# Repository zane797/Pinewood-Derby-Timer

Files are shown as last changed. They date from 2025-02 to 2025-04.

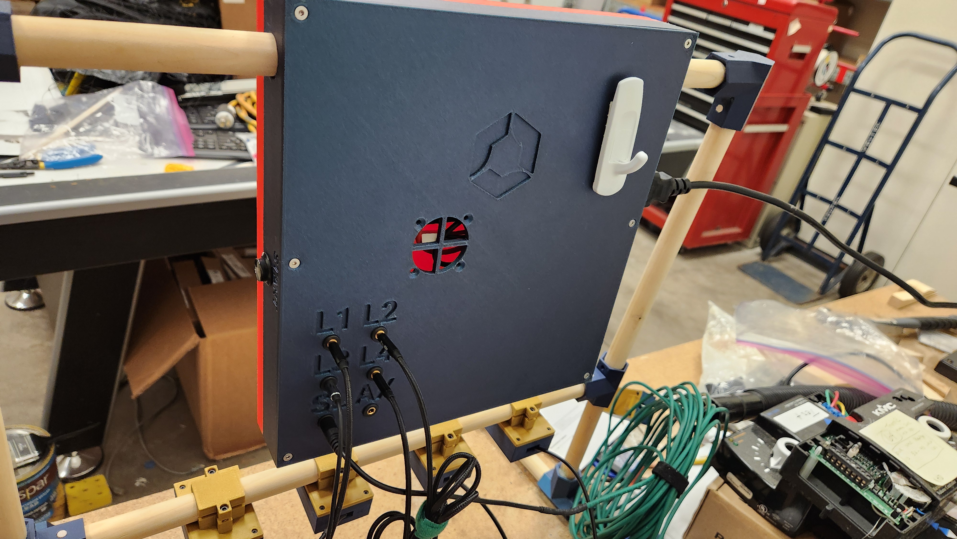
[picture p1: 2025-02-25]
Photos/Exterior/20250219_124340.jpg

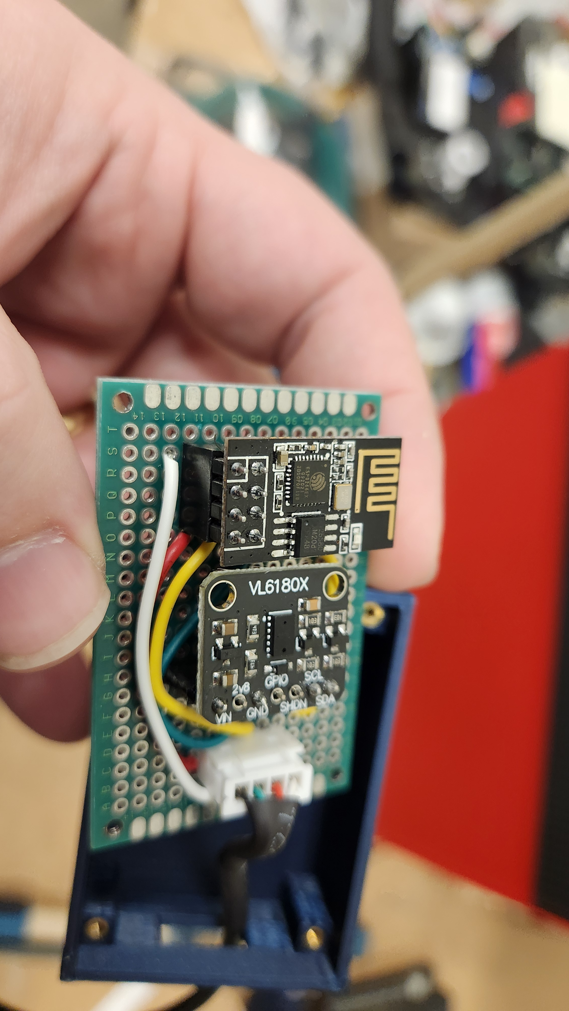
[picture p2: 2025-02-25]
Photos/Interior/20250219_135851.jpg

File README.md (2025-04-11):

# Pinewood-Derby-Timer
A firmware and case design for a DIY pinewood derby timer. Long term this will integrate with the Derby Net race management software.

# Bill of Materials

## Main Control Box

|Description|Part|Link|
|-|-|-|
|Main Microcontroller|Raspberry Pi Pico W|[Aliexpress](https://www.aliexpress.us/item/3256805317728363.html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)|
|Wifi and Derby Net Host|Raspberry Pi Zero W|[Aliexpress](https://www.aliexpress.us/item/3256805605866860.html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)
|Timer Screen|P4 64x32 LED Matrix|[Aliexpress](https://www.aliexpress.us/item/3256804589638597.html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)|
|5V PSU|Meanwell LRS-100-5|[Aliexpress](https://www.aliexpress.us/item/3256805881564763.html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)|
|Pin Connections|Assorted 4 pin JST 2.54 Headers|[Aliexpress](https://www.aliexpress.us/item/3256806894018733.html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)|
|Sensor Connections|3.5 MM Jack|[Aliexpress](https://www.aliexpress.us/item/3256803435015141.html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)|
|Voltage Regulator|LD1117V33|[Aliexpress](https://www.aliexpress.us/item/3256806308155209.html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)|
|Starting Button|16 mm Round Push Button|[Aliexpress](https://www.aliexpress.us/item/2255800895415537.html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)|
|Power Plug|C14 Plug Socket|[Aliexpress](https://www.aliexpress.us/item/2251832772820835.html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)

## Sensor Module

|Description|Part|Link|
|-|-|-|
|TOF Sensor|VL6180X|[Aliexpress](https://www.aliexpress.us/item/3256806030301281.html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)|
|Sensor Microcontroller|ESP8266-ESP01S|[Aliexpress](https://www.aliexpress.us/item/3256805668764137.html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)
|Main Board Connection|3.5 mm TRRS Female|[Aliexpress](https://www.aliexpress.us/item/3256806426250837.html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)|
|Pin Connections|Assorted 4 pin JST 2.54 Headers|[Aliexpress](https://www.aliexpress.us/item/3256806894018733.html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)|
|Main Board Cable|3.5 MM TRRS Cable 1ft|[Aliexpress](https://www.aliexpress.us/item/2255799918035646.html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)

## Starting Line
|Description|Part|Link|
|-|-|-|
|Reed Switch|GPS-14A NO|[Aliexpress](https://www.aliexpress.us/item/3256808008425913.html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)|

Not included are assorted resistors and capacitors, as are documented in the circuit schematic.

# Overall Design

## Main Control Box

The goal for this box was to create a replacement Pinewood Derby Track Timer and add a race management software called DerbyNet. The core of this is a Raspberry Pi Pico W with a Raspberry Pi Zero W. The plan is to create a system that reliably times differences of less than 50 ms. The sensors read at ~100Hz and require 2 successive detections of a car, to avoid false readings at the high speed. This means the effective sensing time is roughly .02 seconds. This meets the design goal of sensing times of less than 0.05 seconds. One major design goal was a simple to setup system. The existing timer required precise alignment of lighting with the sensors below the track and a difficult to 

The original design included an I2C multiplexer routed directly to the VL6180Xs in the sensor modules. This led to sensing issues and bad data reads. I suspect this was due to using I2C through several connections and wire types. This was removed and in it's place I am using simple digital command and input signal lines to command the ESP-01S modules accordingly. These have been much more reliable and once the architecture change happened reliability went up significantly.

The display is a LED matrix screen using a HUB75 interface which makes the wiring more painful than the I2C interface most lightweight hobbyists like myself are used to for project displays. I think if I were to make a version 2, I would create a custom PCB for the PCB and include a HUB75 socket to make the wiring process much easier. Aside from the interface, the LED Matrix as a display worked incredibly well for my. It's easily readable even in well lit rooms, and fit perfectly in my model. I think the only thing I would change is pulling in the display a bit so it doesn't protrude from the chassis.

## Sensor Module

The sensor module started as just a VL6180X on a protoboard, with a couple pull up resistors and a JST connector for the wire. This turned out to be a reliability nightmare and for the initial release I updated it to have a dedicated ESP8266 in a ESP-01S package, which had exactly the number of IO pins for what I needed. The ESP-01S interfaced with the VL6180X directly and signaled the main control box when a car was detected.

# Lessons Learned/V2 Plans

I am unlikely to return to this project soon, but when I do these are some of the items I'd like to implement in the future to streamline the design for anyone else that makes it.

## Lesson's Learned
- While I2C can be used over longer distances, it can be unreliable when jumped through multiple connections with inconsistent capacitance on each leg. I should have planned on something more robust, RS485, or something simple like a simple Digital Output and Digital Input like I ended up with much earlier on.
- I was using DIY TRRS cables using ethernet and DIY oriented 3.5 mm TRRS connectors. This was terrible in terms of reliability. I should have spent a few bucks per cable and gone to store bought from the start. Just because you can DIY doesn't mean you should.
- 

## Next Steps
- [ ] Develop a custom to streamline construction. Right now the main PCB is an exremely manual process. A custom PCB would be both easier to work with and have a smaller footprint. This could also leverage something like the [Raspberry Pi Pico Stamp](https://shop.pimoroni.com/products/rp2040-stamp?variant=39567567028307) to further reduce footprint.
- [ ] [DerbyNet](https://derbynet.org/) Integration. Leverage the second core on the Pi Pico to implement code to tie into the Derby Net instance being hosted on the Raspberry Pi Zero W over USB serial.
- [ ] Consider alternative sensors to further drive down the timing resolution with a goal of sub 10 ms. This will need to meet the design criteria of simple to set up, so it must be only top mounted and not include additional parts under the track. i.e. Lights shining from below the track to trigger an occlusion sensor would fail as it requires the alignment of two separate assemblies.
- [ ] Redesign the electronics enclosure. It always just the fastest and easiest design I could make so I could focus on firmware. It is a bit ponderous on the dowel and space could be used more efficiently.
- [ ] Redesign the frame. I like the concept of a simple modular frame assembly. I did notice that dowels changed in shape much more than I expected over time, likely due to moisture changes. I'd like to improve the geometry of the joints so that 3/4" dowels with some shrinkage could be pressfit into them.

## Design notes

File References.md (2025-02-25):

# Libraries Used in the Code
[Adafruit ProtoMatter](https://github.com/adafruit/Adafruit_protomatter)

[Raspberry Pi Pico Support](https://github.com/earlephilhower/arduino-pico)

[VL6180X](https://github.com/pololu/vl6180x-arduino)

[ESP8266 Support](https://github.com/esp8266/Arduino)

# Race Management Software
[DerbyNet (Not Fully Implemented)](https://derbynet.org/builds/docs.php)

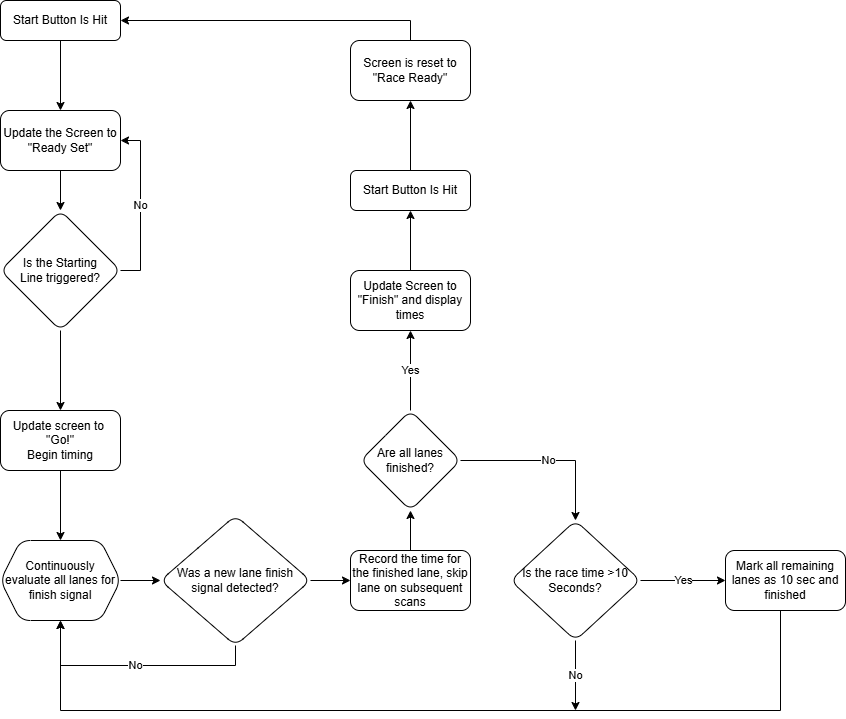
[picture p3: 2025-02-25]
Control Flow Chat.drawio.png

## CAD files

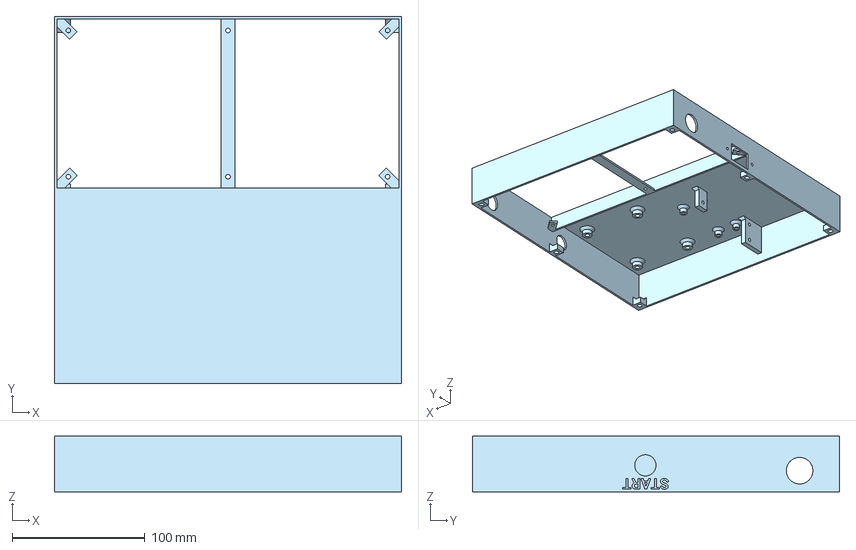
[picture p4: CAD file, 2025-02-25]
3D Models/Main Enclosure/STEP/Main Chassis v1.step
261.0 x 276.0 x 42.0 mm

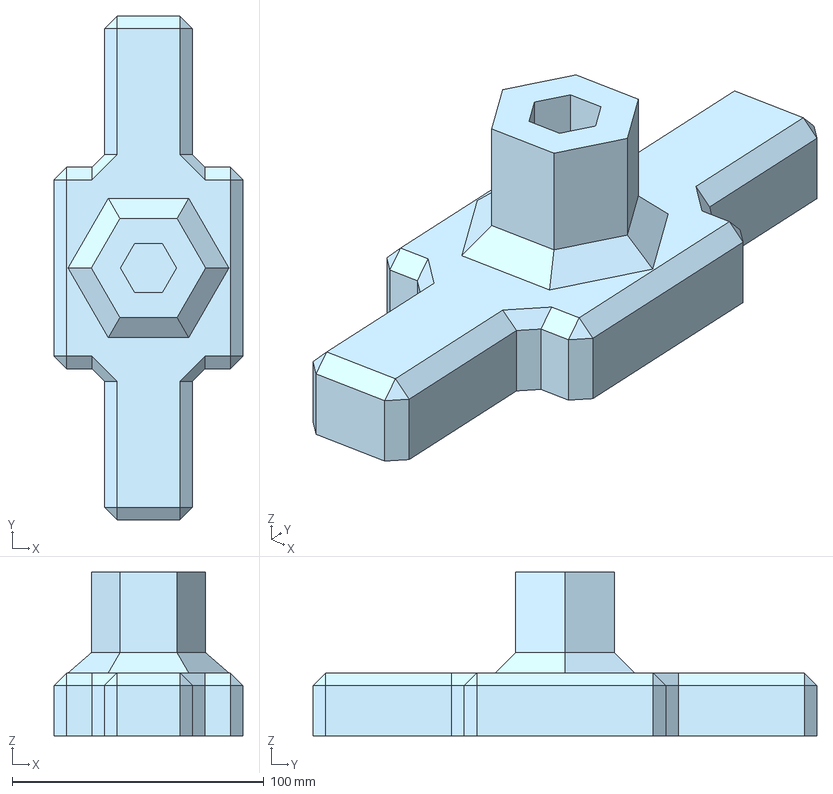
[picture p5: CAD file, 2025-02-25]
3D Models/Frame/STEP/Complete Foot.step
75.0 x 200.0 x 65.0 mm

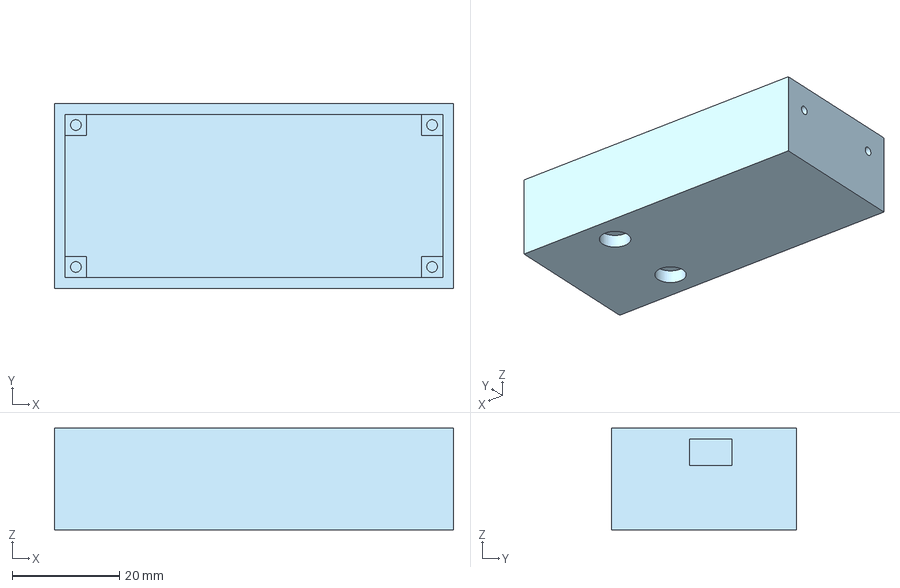
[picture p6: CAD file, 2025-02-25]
3D Models/Starting Line Sensor/STEP/Main Body.step
74.5 x 34.5 x 19.0 mm

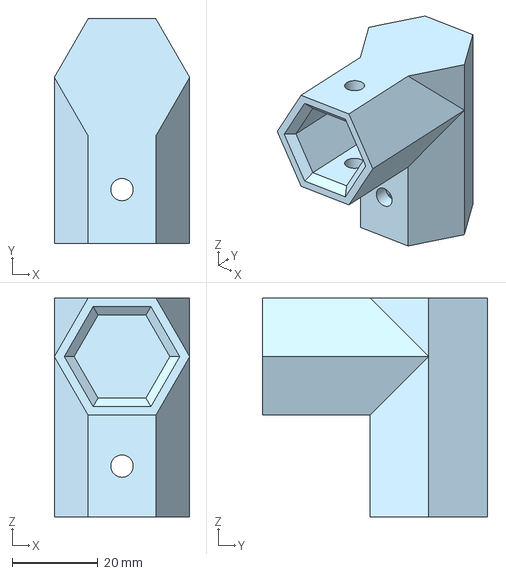
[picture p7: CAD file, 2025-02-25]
3D Models/Frame/STEP/Elbow Joint.step
31.5 x 52.3 x 51.0 mm

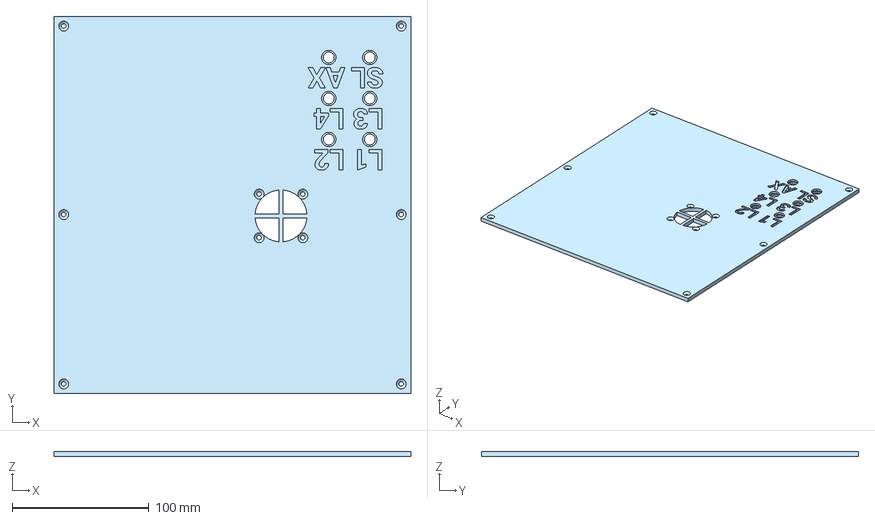
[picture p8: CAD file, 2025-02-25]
3D Models/Main Enclosure/STEP/Back Cover.step
261.0 x 276.0 x 4.00 mm

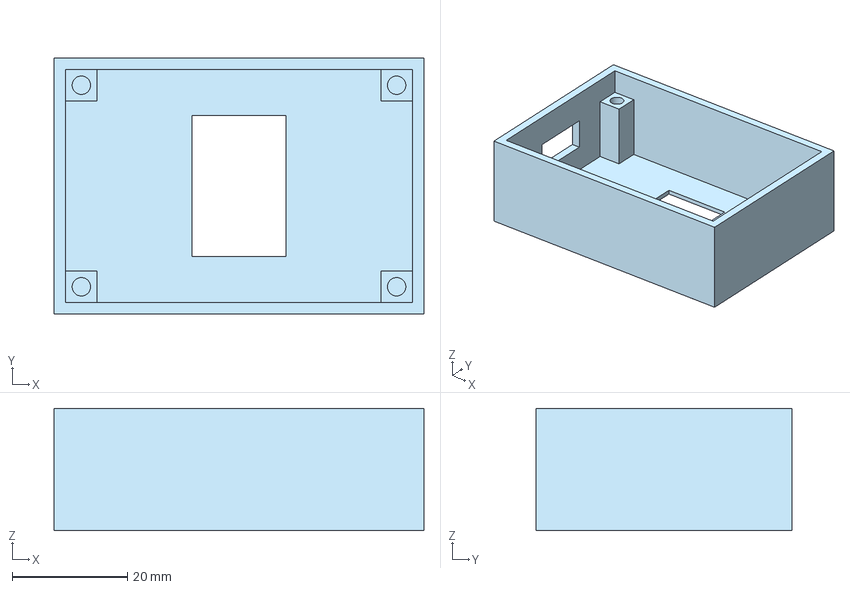
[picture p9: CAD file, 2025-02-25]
3D Models/Sensor Modules/STEP/Body.step
64.2 x 44.5 x 21.2 mm

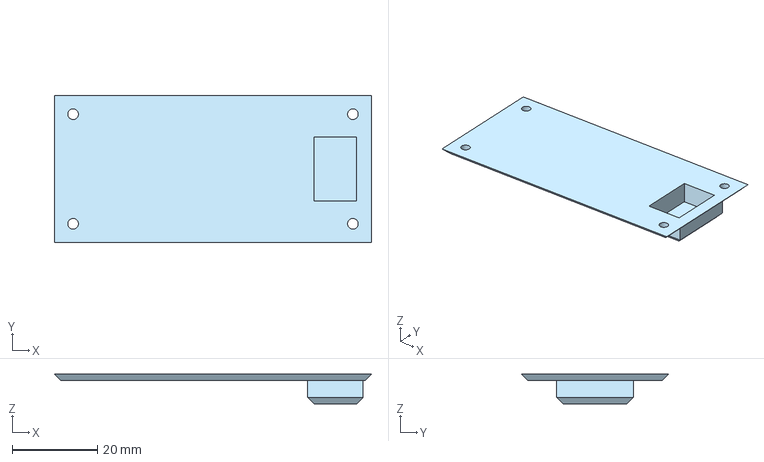
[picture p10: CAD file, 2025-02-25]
3D Models/Starting Line Sensor/STEP/Lid.step
74.5 x 34.5 x 7.00 mm

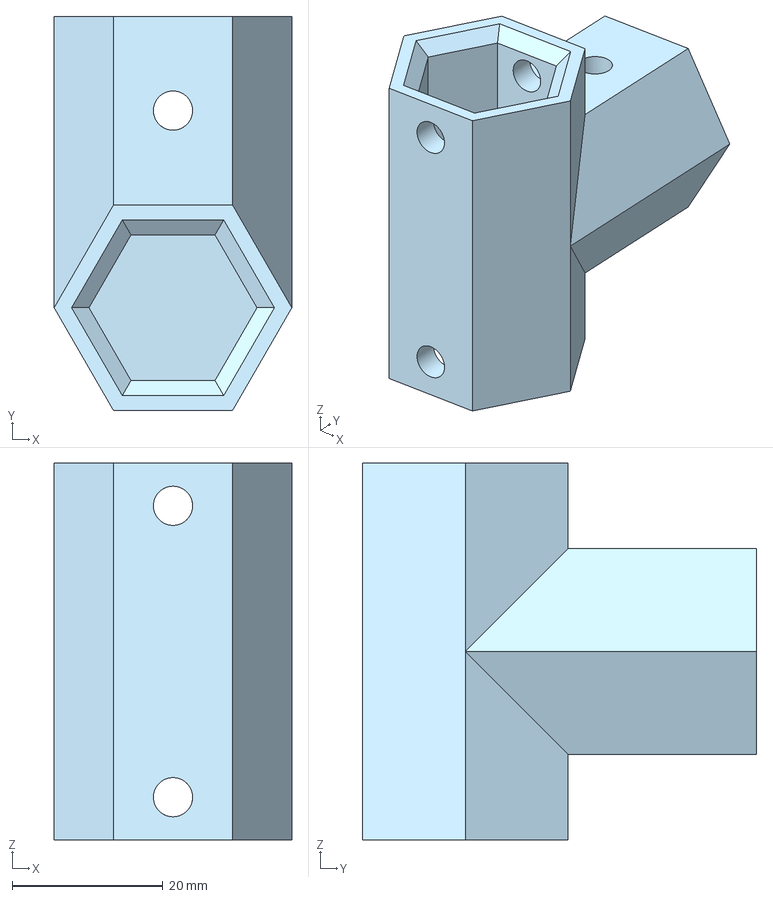
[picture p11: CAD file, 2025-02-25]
3D Models/Frame/STEP/T-Joint.step
31.5 x 52.3 x 50.0 mm

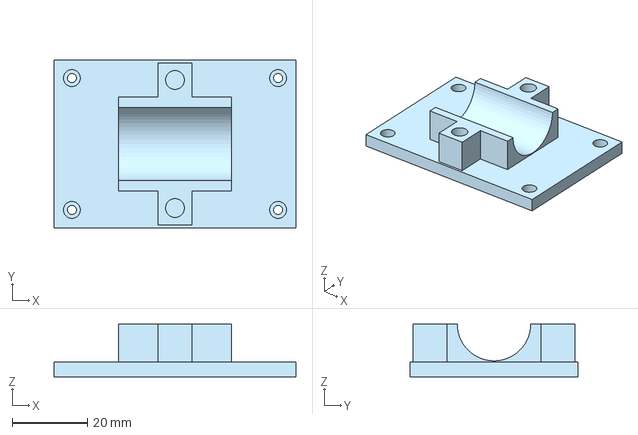
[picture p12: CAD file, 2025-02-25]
3D Models/Sensor Modules/STEP/Back.step
64.2 x 44.5 x 14.0 mm

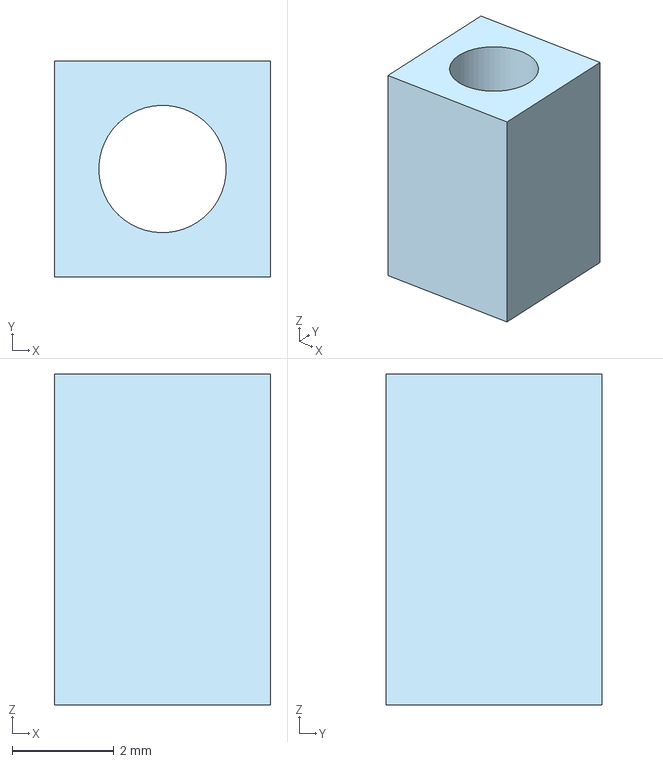
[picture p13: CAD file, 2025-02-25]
3D Models/Starting Line Sensor/STEP/Spacer.step
4.25 x 4.25 x 6.50 mm

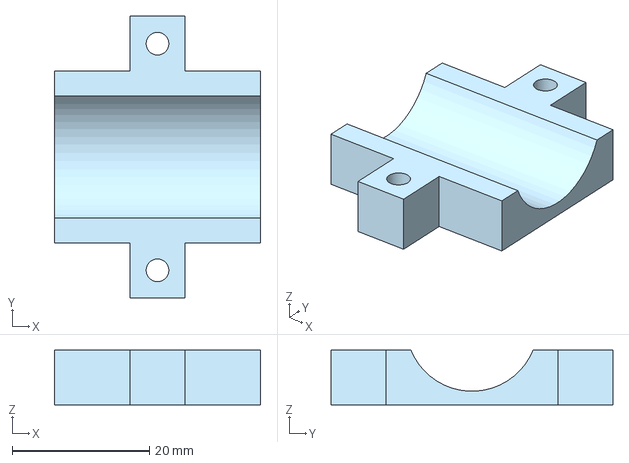
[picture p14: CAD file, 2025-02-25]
3D Models/Sensor Modules/STEP/Dowel Lock.step
30.0 x 41.0 x 8.00 mm

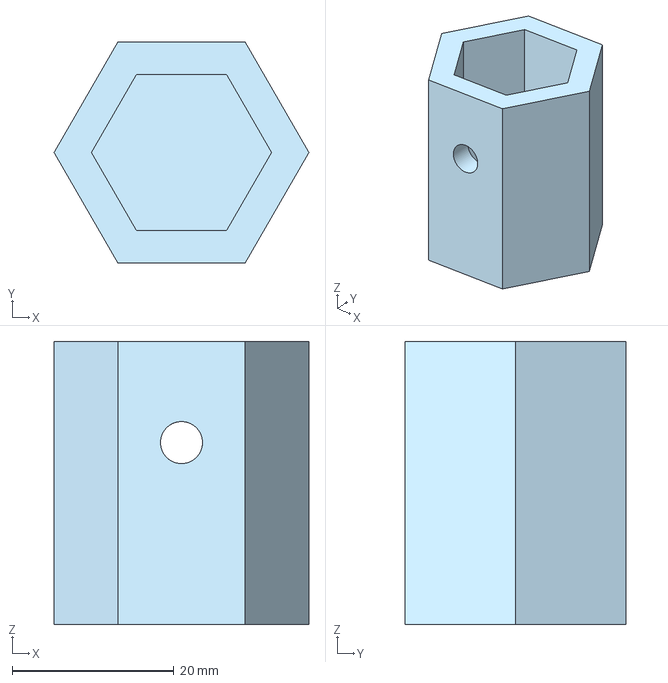
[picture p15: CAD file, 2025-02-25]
3D Models/Frame/STEP/End Cap.step
31.5 x 27.3 x 35.0 mm

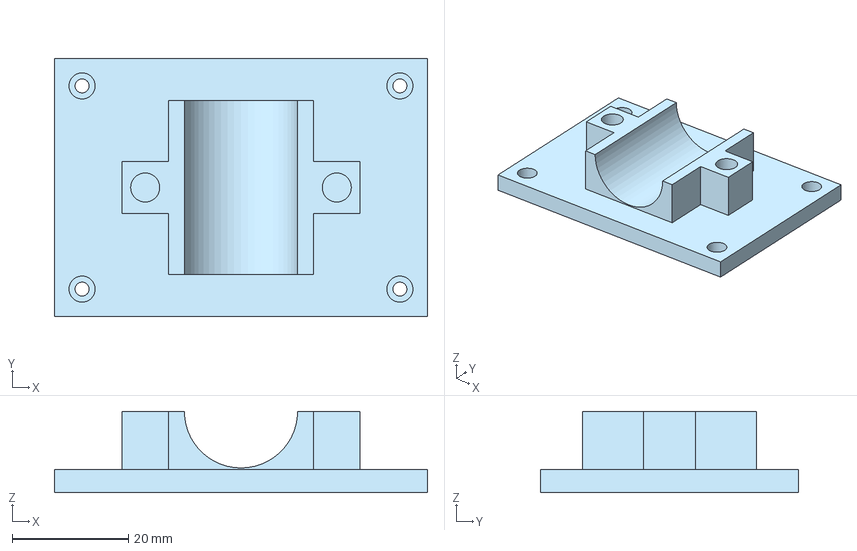
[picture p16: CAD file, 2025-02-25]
3D Models/Sensor Modules/STEP/Back 90 Degree.step
64.2 x 44.5 x 14.0 mm

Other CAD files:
3D Models/Frame/STL/Complete Foot.stl
3D Models/Frame/STL/Elbow Joint.stl
3D Models/Frame/STL/End Cap.stl
3D Models/Frame/STL/T-Joint.stl
3D Models/Main Enclosure/STL/Back Cover.stl
3D Models/Main Enclosure/STL/Main Chassis v1.stl
3D Models/Sensor Modules/STL/Back 90 Degree.stl
3D Models/Sensor Modules/STL/Back.stl
3D Models/Sensor Modules/STL/Body.stl
3D Models/Sensor Modules/STL/Dowel Lock.stl
3D Models/Starting Line Sensor/STL/Lid.stl
3D Models/Starting Line Sensor/STL/Main Body.stl
3D Models/Starting Line Sensor/STL/Spacer.stl

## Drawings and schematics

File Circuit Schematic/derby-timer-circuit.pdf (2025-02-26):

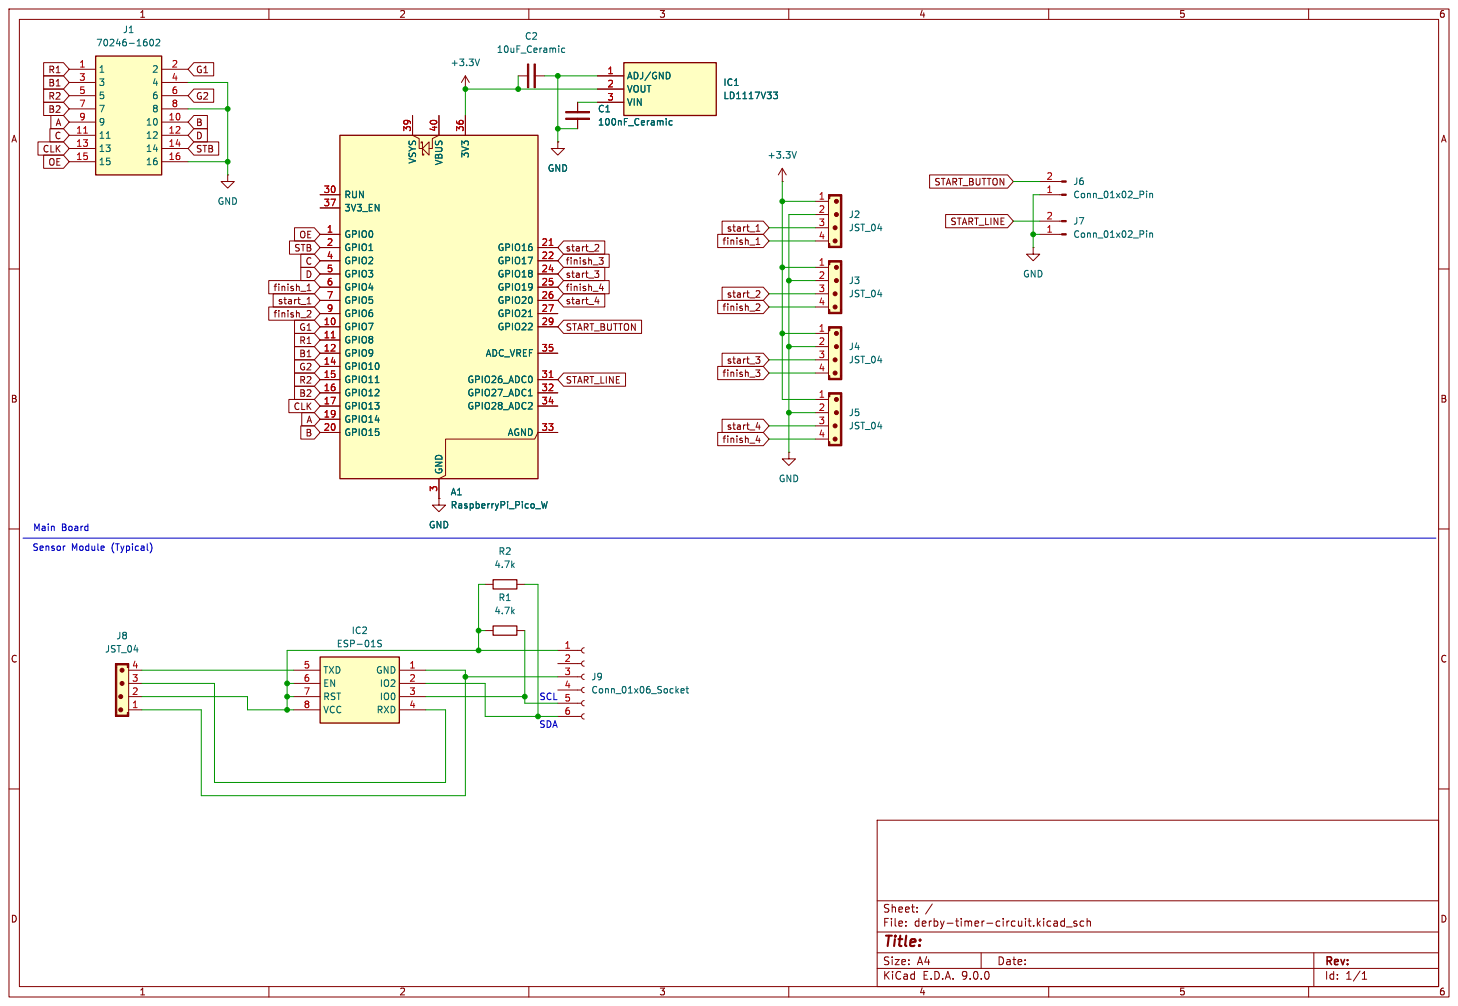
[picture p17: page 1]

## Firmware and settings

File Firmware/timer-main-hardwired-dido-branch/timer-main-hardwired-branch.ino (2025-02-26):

//Include libraries
#include <Adafruit_Protomatter.h>
#include <Wire.h>

//System control variables
#define debug 0               //Full debug. USB Serial enabled. May delay code sufficiently to impact finish timing.
#define debug_no_serial 0     //Put into debug mode to skip the start line but do not send USB serial debug in race run loop
#define button 22             //GPIO Pin for the Chassis Button
#define config_start_input 1  //1=Starting line sensor present, Set to see if the starting line has a sensor. If not, a 3 second delay will be started after hitting the button before transitioning to racing mode
#define sim_race 0            //1=Run the race and DNF all lanes after 10 seconds
#define start_line 26         //GPIO Pin for the starting line IO.
#define BRIGHTNESS 75         //Range 0-255
uint8_t mode = 0;   //0=Ready to Race, 1= Start Race, 2=Running Race,3=Displaying Times
long current_time;  //initialize timing variable

//Sensor IO pins
int startPins[] = { 0, 5, 16, 18, 20 }; 
int finishPins[] = { 0, 4, 6, 17, 19 };

//Assign LED Matrix Variables
uint8_t rgbPins[] = { 8, 7, 9, 11, 10, 12 }; //R1,G1,B1,R2,G2,B2
uint8_t addrPins[] = { 14, 15, 2, 3 }; //A, B, C, D
uint8_t clockPin = 13;
uint8_t latchPin = 1;
uint8_t oePin = 0;

Adafruit_Protomatter matrix(
  64,                         // Width of matrix (or matrix chain) in pixels
  4,                          // Bit depth, 1-6
  1, rgbPins,                 // # of matrix chains, array of 6 RGB pins for each
  4, addrPins,                // # of address pins (height is inferred), array of pins
  clockPin, latchPin, oePin,  // Other matrix control pins
  false);                     // No double-buffering here (see "doublebuffer" example)

//Establish timer variables
uint timerraw = 0;
String timerstr = "";
String decimals[5][5];
uint race_times[5];
int finish[5] = { 0, 0, 0, 0, 0 };
uint start_time;
char times[] = "";


//Function to display the times for a given lane [Optimization] if the time is less than 1 second, append a leading 0 to it to display correctly
void displaytimes(int ln, int int_time) {
  //Establish Function Variables
  int x_offset = (ln - 1) * 16 + 2;
  String lane_name = "L" + String(ln);
  //Run if the time is valid
  if (int_time < 10000) {
    //Convert time to string
    itoa(int_time, times, 10);
    /*Proposed optimization code
    if (int_time<1000){
      times="0"+times;
    }
    */

    //Clear the matrix
    matrix.fillRect(x_offset, 10, 16, 22, matrix.color565(0, 0, 0));
    //Print the lane details
    matrix.setTextColor(matrix.color565(0, 0, BRIGHTNESS));
    matrix.setCursor(x_offset, 10);
    matrix.println(lane_name);
    matrix.setTextColor(matrix.color565(0, BRIGHTNESS, 0));
    matrix.setCursor(x_offset, 18);
    matrix.println(times[0]);
    matrix.drawPixel(x_offset + 5, 24, matrix.color565(BRIGHTNESS, 0, 0));
    matrix.setCursor(x_offset + 6, 18);
    matrix.println(times[1]);
    matrix.setCursor(x_offset, 25);
    matrix.println(String(times[2]) + String(times[3]));
    matrix.show();
  } else {
    //Clear the matrix
    matrix.fillRect(x_offset, 10, 16, 22, matrix.color565(0, 0, 0));
    //Print the lane details
    matrix.setTextColor(matrix.color565(0, 0, 100));
    matrix.setCursor(x_offset, 10);
    matrix.println(lane_name);
    matrix.setTextColor(matrix.color565(0, 100, 0));
    matrix.setCursor(x_offset, 18);
    matrix.println("DN");
    matrix.setCursor(x_offset + 3, 25);
    matrix.println("F");
    matrix.show();
  }
}

//Function to reset the screen to a prerace state
void reset_screen() {
  //Blank the entire screen
  matrix.fillScreen(matrix.color565(0, 0, 0));
  //Show Startup Screen
  for (int x = 0; x < matrix.width(); x++) {
    int r = 0;
    int b = 0;
    int g = 0;
    if (x < 16) {
      r = BRIGHTNESS;
    } else if (x >= 16 && x < 32) {
      g = BRIGHTNESS;
    } else if (x >= 32 && x < 48) {
      b = BRIGHTNESS;
    } else {
      r = BRIGHTNESS;
      g = BRIGHTNESS;
      b = BRIGHTNESS;
    }
    matrix.drawPixel(x, 0, matrix.color565(r, g, b));
    matrix.drawPixel(x, 8, matrix.color565(r, g, b));
  }
  matrix.setCursor(1, 1);
  matrix.setTextSize(1);
  matrix.setTextColor(matrix.color565(BRIGHTNESS, BRIGHTNESS, BRIGHTNESS));
  matrix.println("RACE");
  matrix.setCursor(34, 1);
  matrix.println("READY");
  matrix.show();  // Copy data to matrix buffers

  //Set mode to 0, Ready to Race
  mode = 0;
}

//Function to initialize the race and store necessary variables
void racing_start() {
  //Blank the entire screen
  matrix.fillScreen(matrix.color565(0, 0, 0));
  //Show Startup Screen
  for (int x = 0; x < matrix.width(); x++) {
    int r = 0;
    int b = 0;
    int g = 0;
    if (x < 16) {
      r = BRIGHTNESS;
    } else if (x >= 16 && x < 32) {
      g = BRIGHTNESS;
    } else if (x >= 32 && x < 48) {
      b = BRIGHTNESS;
    } else {
      r = BRIGHTNESS;
      g = BRIGHTNESS;
      b = BRIGHTNESS;
    }
    matrix.drawPixel(x, 0, matrix.color565(r, g, b));
    matrix.drawPixel(x, 8, matrix.color565(r, g, b));
  }
  matrix.setCursor(1, 1);
  matrix.setTextSize(1);
  matrix.setTextColor(matrix.color565(BRIGHTNESS, BRIGHTNESS, BRIGHTNESS));
  matrix.println("READY SET!");
  matrix.show();  // Copy data to matrix buffers

  mode = 1;
}

//Function to run during the actual race
void running_race() {
  //Record the start time
  start_time = millis();
  
  //Zero Out the finish variable
  for (int x = 1; x < 5; x++) {
    finish[x] = 0;
  }
  //Send the race start signal
  for (int x = 1; x < 5; x++) {
    digitalWrite(startPins[x], HIGH);
  }
  delay(500); //[Optimization] Lower this delay with trial testing on the esp8266 main boards, I'd like to see this at <100 ms

  //Clear the race start signal
  for (int x = 1; x < 5; x++) {
    digitalWrite(startPins[x], LOW);
  }

  if (debug == 1) { Serial.println("Start time: " + String(start_time)); }

  //Keep running the loop until all lanes have finished
  while (finish[1] != 1 || finish[2] != 1 || finish[3] != 1 || finish[4] != 1) {

    //Increment through the sensors and evaluate states
    for (int x = 1; x < 5; x++) {
      //if the lane has not finished previously, evaluate the IO to see if it has now
      if (finish[x] != 1) {
        if (digitalRead(finishPins[x]) == 1) {
          race_times[x] = millis() - start_time;
          finish[x] = 1;
        }
      }
    }
    //If the race has run for more than 10 seconds, end the loop
    if ((millis() - start_time) > 10000) {
      break;
    }
  }
  //Check all lanes, if one did not finish assign it a time of 10000 (DNF)
  for (int x = 1; x < 5; x++) {
    if (finish[x] != 1) {
      finish[x] = 1;
      race_times[x] = 10000;
    }
  }
  //Run the display times function for all lanes
  for (int x = 1; x < 5; x++) {
    displaytimes(x, race_times[x]);
  }
  //Change the display to say "Finish"
  matrix.fillRect(0, 1, 64, 7, matrix.color565(0, 0, 0));
  matrix.setTextColor(matrix.color565(0, 0, BRIGHTNESS));
  matrix.setCursor(14, 1);
  matrix.println("FINISH!");
  matrix.show();

  //Set mode to 3, displaying times
  mode = 3;

  for (int x = 1; x < 5; x++) { digitalWrite(startPins[x], LOW); }
}

void setup() {
  // put your setup code here, to run once:
  if (debug == 1) {
    Serial.begin(9600);
  }

  // Initialize matrix...
  ProtomatterStatus status = matrix.begin();
  if (debug == 1) {
    Serial.print("Protomatter begin() status: ");
    Serial.println((int)status);
  }
  if (status != PROTOMATTER_OK) {
    // DO NOT CONTINUE if matrix setup encountered an error.
    for (;;)
      ;
  }

  //Show Startup Screen
  reset_screen();

  //Set Pin Modes
  pinMode(button, INPUT_PULLUP);
  pinMode(start_line, INPUT_PULLUP);
  for (int x = 1; x < 5; x++) {
    pinMode(startPins[x], OUTPUT);
    digitalWrite(startPins[x], LOW);
    pinMode(finishPins[x], INPUT);
  }

  delay(100);
  //Set mode to 0, ready to race
  mode = 0;
}

void loop() {
  //If in mode 0, prepared to start, pushing the button will prep the system to run looking for debug or start signal
  if (digitalRead(button) == 0 && mode == 0) {
    racing_start();
  } 
  else if ((digitalRead(start_line) == 0 || config_start_input == 0) && mode == 1 && sim_race == 0) {
    if (config_start_input == 0) { delay(3000); }
    matrix.fillRect(0, 1, 64, 7, matrix.color565(0, 0, 0));
    matrix.setTextColor(matrix.color565(0, BRIGHTNESS, 0));
    matrix.setCursor(26, 1);
    matrix.println("GO!");
    matrix.show();
    mode = 2;
    running_race();
  }
  //Debug mode, skip start line input
  else if ((debug == 1 || debug_no_serial == 1) && mode == 1 && sim_race == 1) {
    Serial.println("Entering Sim Racing Mode, skipping start_line input");
    delay(500);
    matrix.fillRect(0, 1, 64, 7, matrix.color565(0, 0, 0));
    matrix.setTextColor(matrix.color565(0, BRIGHTNESS, 0));
    matrix.setCursor(26, 1);
    matrix.println("GO!");
    matrix.show();
    mode = 2;
    Serial.println("Mode: " + String(mode));
    running_race();
    delay(50);
  } 
  else if (digitalRead(button) == 0 && mode == 3) {
    matrix.fillRect(0, 1, 64, 7, matrix.color565(0, 0, 0));
    matrix.fillRect(0, 9, 64, 23, matrix.color565(0, 0, 0));
    matrix.setTextColor(matrix.color565(BRIGHTNESS, BRIGHTNESS, BRIGHTNESS));
    matrix.setCursor(20, 1);
    matrix.println("RESET");
    matrix.show();
    mode = 4;
    delay(500);
  } else if (digitalRead(start_line) == 1 && mode == 4) {
    reset_screen();
  }
}

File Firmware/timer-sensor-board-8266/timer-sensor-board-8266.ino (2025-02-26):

//Include libraries
#include <Wire.h>
#include <VL6180X.h>

//Create VL6180X object new
VL6180X sensor;

//Define code constants
#define pinStart 3
#define pinFinish 1
#define pinSDA 2
#define pinSCL 0
#define deadband 10
#define finishCheckSP 2

//Initialize variables
long unsigned int timestart = 0;
int racing = 0;
int finishSP = 0;
int sensor_val = 0;
int finishCheck = 0;  //Range must be below finishSP for finishCheckSP to consider finished

//initializing sensor function
void initialize_rangesensors() {

  //Initialize Sensor with starting values
  sensor.init();
  sensor.configureDefault();

  // Reduce range max convergence time and ALS integration
  sensor.writeReg(VL6180X::SYSRANGE__MAX_CONVERGENCE_TIME, 5);
  sensor.writeReg(VL6180X::READOUT__AVERAGING_SAMPLE_PERIOD, 10);  //Use a rolling average of the last 10 counts
  sensor.writeReg(VL6180X::SYSRANGE__VHV_REPEAT_RATE, 0);          //Disable the automatic Very High Voltage sensor calibration
  sensor.writeReg(VL6180X::SYSRANGE__VHV_RECALIBRATE, 1);          //Manually run VHV calibration
  sensor.setTimeout(20);
  sensor.setScaling(1);

  //Set sensor ranging mode and start continuous reading
  sensor.stopContinuous();
  delay(10);
  sensor.startRangeContinuous(10);
}

void setup() {
  //Configure DI/DO pins
  pinMode(pinStart, INPUT);
  pinMode(pinFinish, OUTPUT);
  digitalWrite(pinFinish, LOW);  //Set finish pin to low to clear the finish flag
  //I2C Configuration
  Wire.begin(pinSDA, pinSCL);
  delay(50);

  //Sensor Configuration function
  initialize_rangesensors();
}

void loop() {
  //If not racing, and start is triggered, take inital reading a calculate finishSP
  if (racing == 0 && digitalRead(pinStart) == 1) {
    digitalWrite(pinFinish, LOW);               //Clear the finish flag
    sensor_val = sensor.readRangeContinuous();  //Get a baseline reading to act as the "normal" distance reading
    finishSP = sensor_val - deadband;           //Calculate finish SP with baseline reading and deadband
    timestart = millis();
    finishCheck = 0;
    delay(700);  //wait 700 ms for the main board to send and clear start signals. [Optimization] tighten this timing along with the main board delay between start signal activation and clearing
    racing = 1;
  }
  if (sensor.timeoutOccurred() == 1) {
    initialize_rangesensors();
    //[Optimization] consider further if the SP should be recalculated when sensor is reinitialized
    //finishSP=sensor_val-deadband;
  }

  while (racing == 1) {
    //Get sensor reading to test for finish state
    sensor_val = sensor.readRangeContinuous();

    //If sensor times out, reinitialize
    if (sensor.timeoutOccurred() == 1) {
      initialize_rangesensors();
      //finishSP=sensor_val-deadband;
    }

    //If a new start command is sent more than 20 seconds after the last one was sent, reset back to the start of a new race sequence
    if (digitalRead(pinStart) == 1 && millis() - timestart > 20000) {
      racing == 0;
      break;
    }

    delay(1);
    //If the sensor values is below setpoint increment the finishCheck counter
    if (sensor_val < finishSP) {
      finishCheck += 1;
      //If the sensor has read below SP for two consecutive readings, signal the finish bit and clear the ints
      if (finishCheck >= 2) {
        digitalWrite(pinFinish, HIGH);
        racing = 0;
        finishSP = 255;
      }
    }
    //if the sensor value is not below the SP, reset finishCheck to 0
    else {
      finishCheck = 0;
    }
  }
}

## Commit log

2025-02-25 Added 3D models for all components
    Includes STLs and STEP files
    [Back 90 Degree.step, Back 90 Degree.stl, Back Cover.step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]
2025-02-25 Create BOM
2025-02-25 Control Flow Chart
2025-02-25 Rename Untitled Diagram.drawio to Control Flow Chat.drawio
2025-02-25 Update Control Flow Chat.drawio
2025-02-25 Uploaded static control flow diagram
